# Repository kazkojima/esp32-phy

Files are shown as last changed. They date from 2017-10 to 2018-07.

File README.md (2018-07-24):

# ESP32 PHY

## hardware

ESP-WROOM-32 board with Ethernet made with KiCAD

  * esp32-tlk110

  * esp32-wslan8720

  There are choices for esp32-wslan8720 board. See 

https://kazkojima.github.io/esp32-phy2.html

for detail.

## apps

Applications with ESP32 PHY.

  * sbusconv - A serial to ether converter

See README in the application directory for detail.

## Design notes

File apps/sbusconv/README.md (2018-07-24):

# sbusconv

ESP32 serial-to-ether converter which uses ethernet PHYs. Supports LAN8720 and TK110 PHY. I'm using the hardwares [here](https://github.com/kazkojima/esp32-phy), though the any hardwares can be used with tiny changes on configuration or small fixes.

It converts the popular s.bus format serial RC signals to the RC UDP packets which Parrot bebop drone defines. The packet looks like:

```
struct __attribute__((packed)) rcpkt {
    uint32_t version;
    uint64_t timestamp_us;
    uint16_t sequence;
    uint16_t pwms[8];
};
```

One can easily change it to the mavlink packet, for example, if needed.

Currently no WiFi fuction is used, though you could easily add some controle or data transfer functions via WiFi, if you like.

There is only one unusual configuration item COPY_CH6_CH7 which copies the CH6 value to the CH7 value. My transmitter can't send CH7/CH8 values via s.bus although these channels are generally used for the convenient function like the emergency motor stop. This option makes it possible to use those function on my transmitter.

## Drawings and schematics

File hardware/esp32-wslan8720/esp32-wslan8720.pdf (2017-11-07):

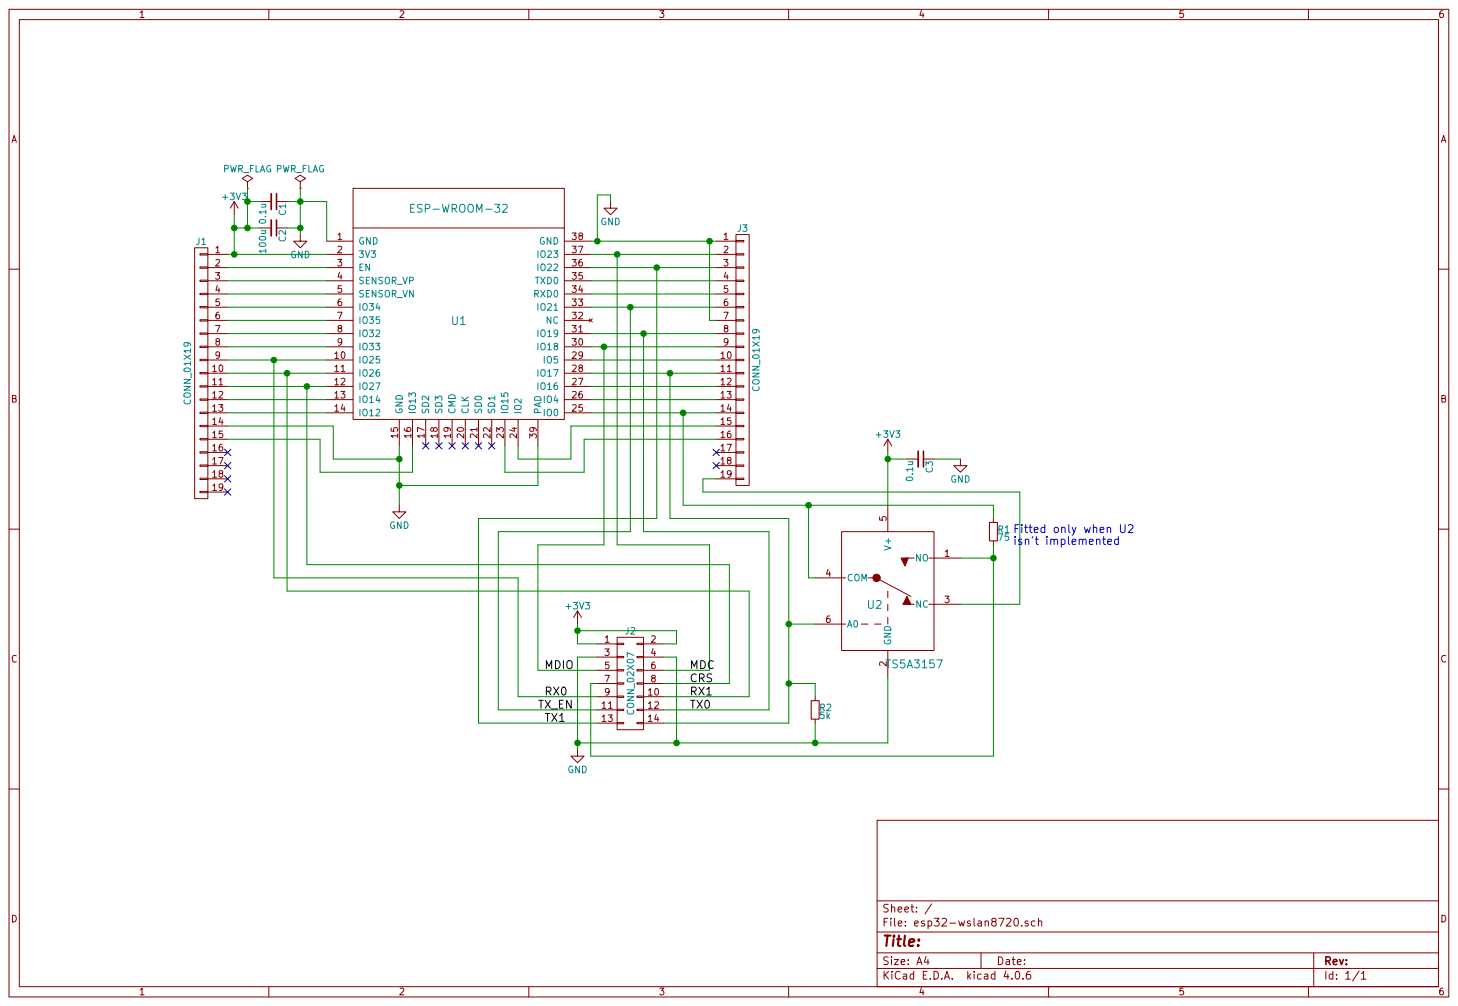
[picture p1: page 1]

2 | 3V3 2 EN 3 SENSOR_VP 4 SENSOR_VN 5 | 3

13 | | 14
14 | | | 15
15 | | | | 16

11 | | 12

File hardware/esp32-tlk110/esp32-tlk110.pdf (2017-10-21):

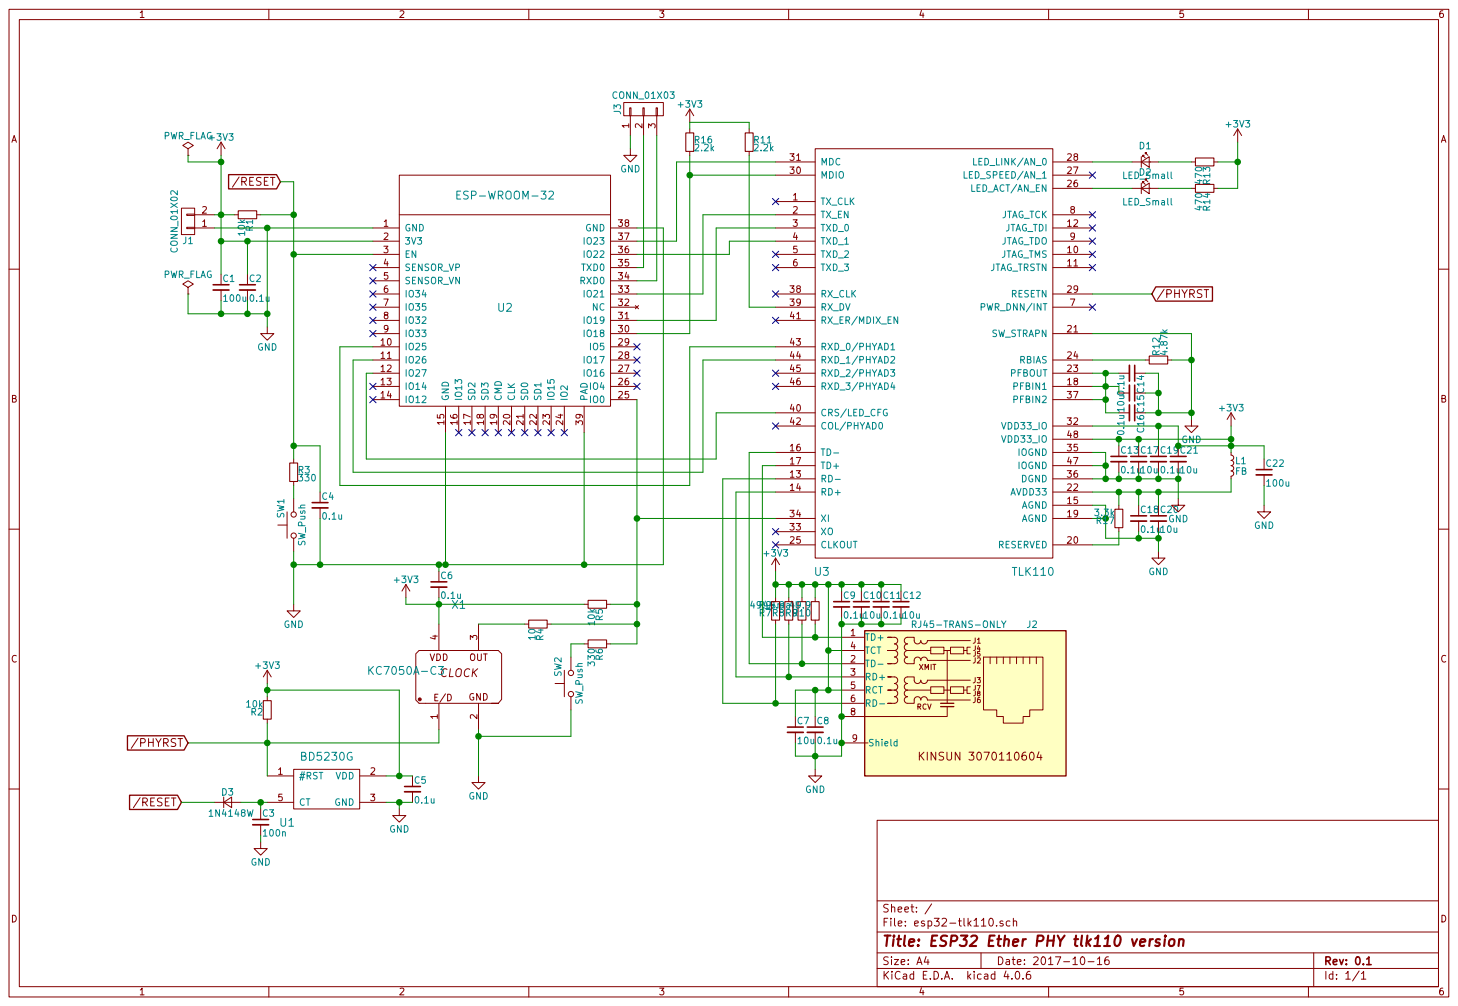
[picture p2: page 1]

File: esp32-tlk110.sch Sheet: /
Id: 1/1 Title: ESP32 Ether PHY tlk110 version

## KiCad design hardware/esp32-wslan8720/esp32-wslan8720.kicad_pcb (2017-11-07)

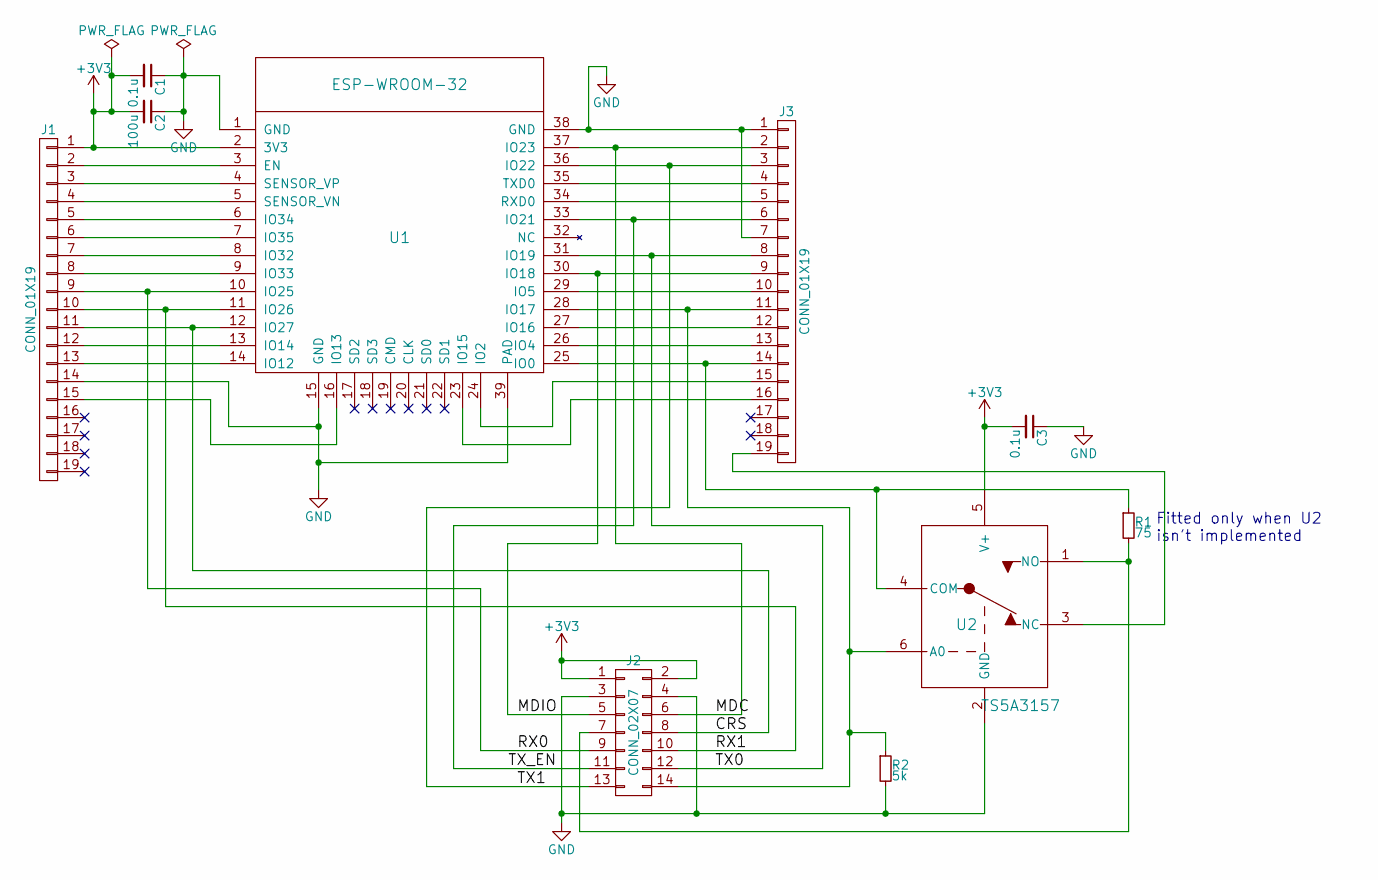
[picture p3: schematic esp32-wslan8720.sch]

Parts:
C1, C3: 0.1u; C_0603_HandSoldering
C2: 100u; C_1210_HandSoldering
J1, J3: CONN_01X19; Pin_Header_Straight_1x19_Pitch2.54mm
J2: CONN_02X07; Pin_Header_Angled_2x07_Pitch2.54mm
R1: 75; R_0603_HandSoldering
R2: 5k; R_0603_HandSoldering
U1: ESP-WROOM-32; ESP32-WROOM-fixed
U2: TS5A3157; SOT-23-6_Handsoldering

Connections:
+3V3: C1.2, C2.2, C3.2, J1.1, J2.1, J2.2, U1.2 (3V3), U2.5 (V+)
/CRS: J1.11, J2.8, U1.12 (IO27)
/MDC: J2.6, J3.2, U1.37 (IO23)
/MDIO: J2.5, J3.9, U1.30 (IO18)
/RX0: J1.9, J2.9, U1.10 (IO25)
/RX1: J1.10, J2.10, U1.11 (IO26)
/TX0: J2.12, J3.8, U1.31 (IO19)
/TX1: J2.13, J3.3, U1.36 (IO22)
/TX_EN: J2.11, J3.6, U1.33 (IO21)
GND: C1.1, C2.1, C3.1, J1.14, J2.3, J2.4, J3.1, J3.7, R2.2, U1.1 (GND), U1.15 (GND), U1.38 (GND), U1.39 (PAD), U2.2 (GND)
unnamed: J1.2, U1.3 (EN)
unnamed: J1.3, U1.4 (SENSOR_VP)
unnamed: J1.4, U1.5 (SENSOR_VN)
unnamed: J1.5, U1.6 (IO34)
unnamed: J1.6, U1.7 (IO35)
unnamed: J1.7, U1.8 (IO32)
unnamed: J1.8, U1.9 (IO33)
unnamed: J1.12, U1.13 (IO14)
unnamed: J1.13, U1.14 (IO12)
unnamed: J1.15, U1.16 (IO13)
unnamed: J2.7, R1.2, U2.1 (NO)
unnamed: J2.14, J3.11, R2.1, U1.28 (IO17), U2.6 (A0)
unnamed: J3.4, U1.35 (TXD0)
unnamed: J3.5, U1.34 (RXD0)
unnamed: J3.10, U1.29 (IO5)
unnamed: J3.12, U1.27 (IO16)
unnamed: J3.13, U1.26 (IO4)
unnamed: J3.14, R1.1, U1.25 (IO0), U2.4 (COM)
unnamed: J3.15, U1.24 (IO2)
unnamed: J3.16, U1.23 (IO15)
unnamed: J3.19, U2.3 (NC)

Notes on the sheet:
Fitted only when U2 isn't implemented

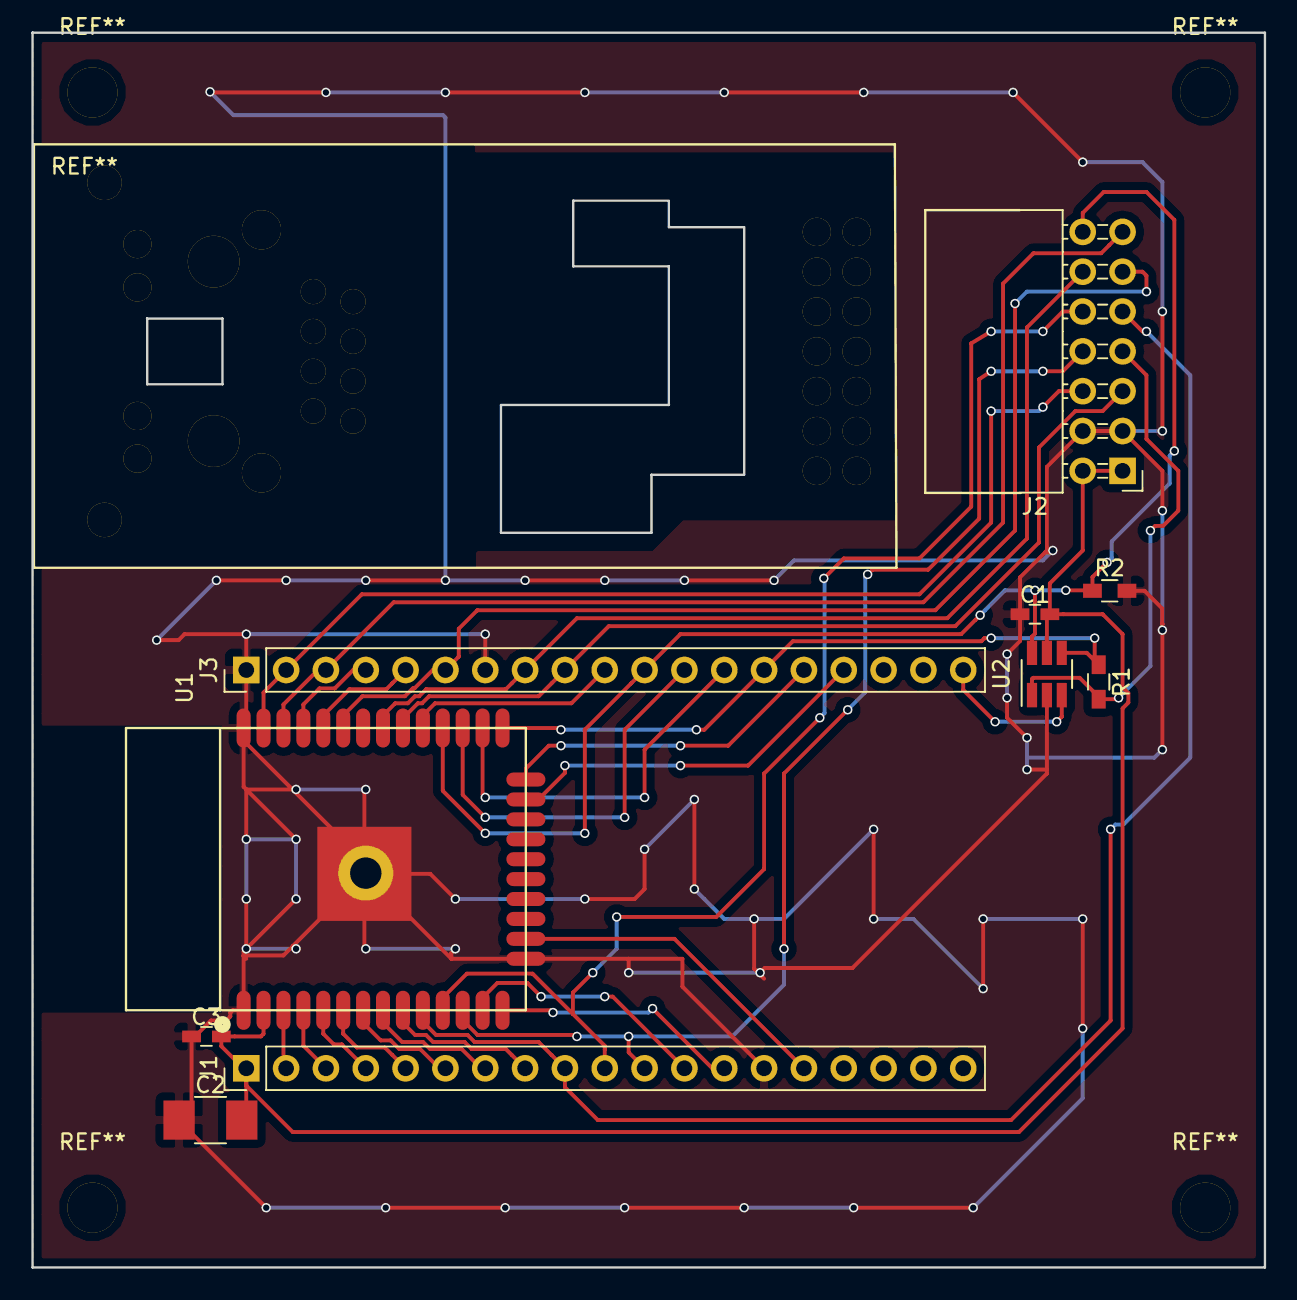
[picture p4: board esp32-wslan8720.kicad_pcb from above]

Board: 2 copper layers, 78.6 x 78.8 mm, 10 parts (0 on the bottom side), 31 nets.

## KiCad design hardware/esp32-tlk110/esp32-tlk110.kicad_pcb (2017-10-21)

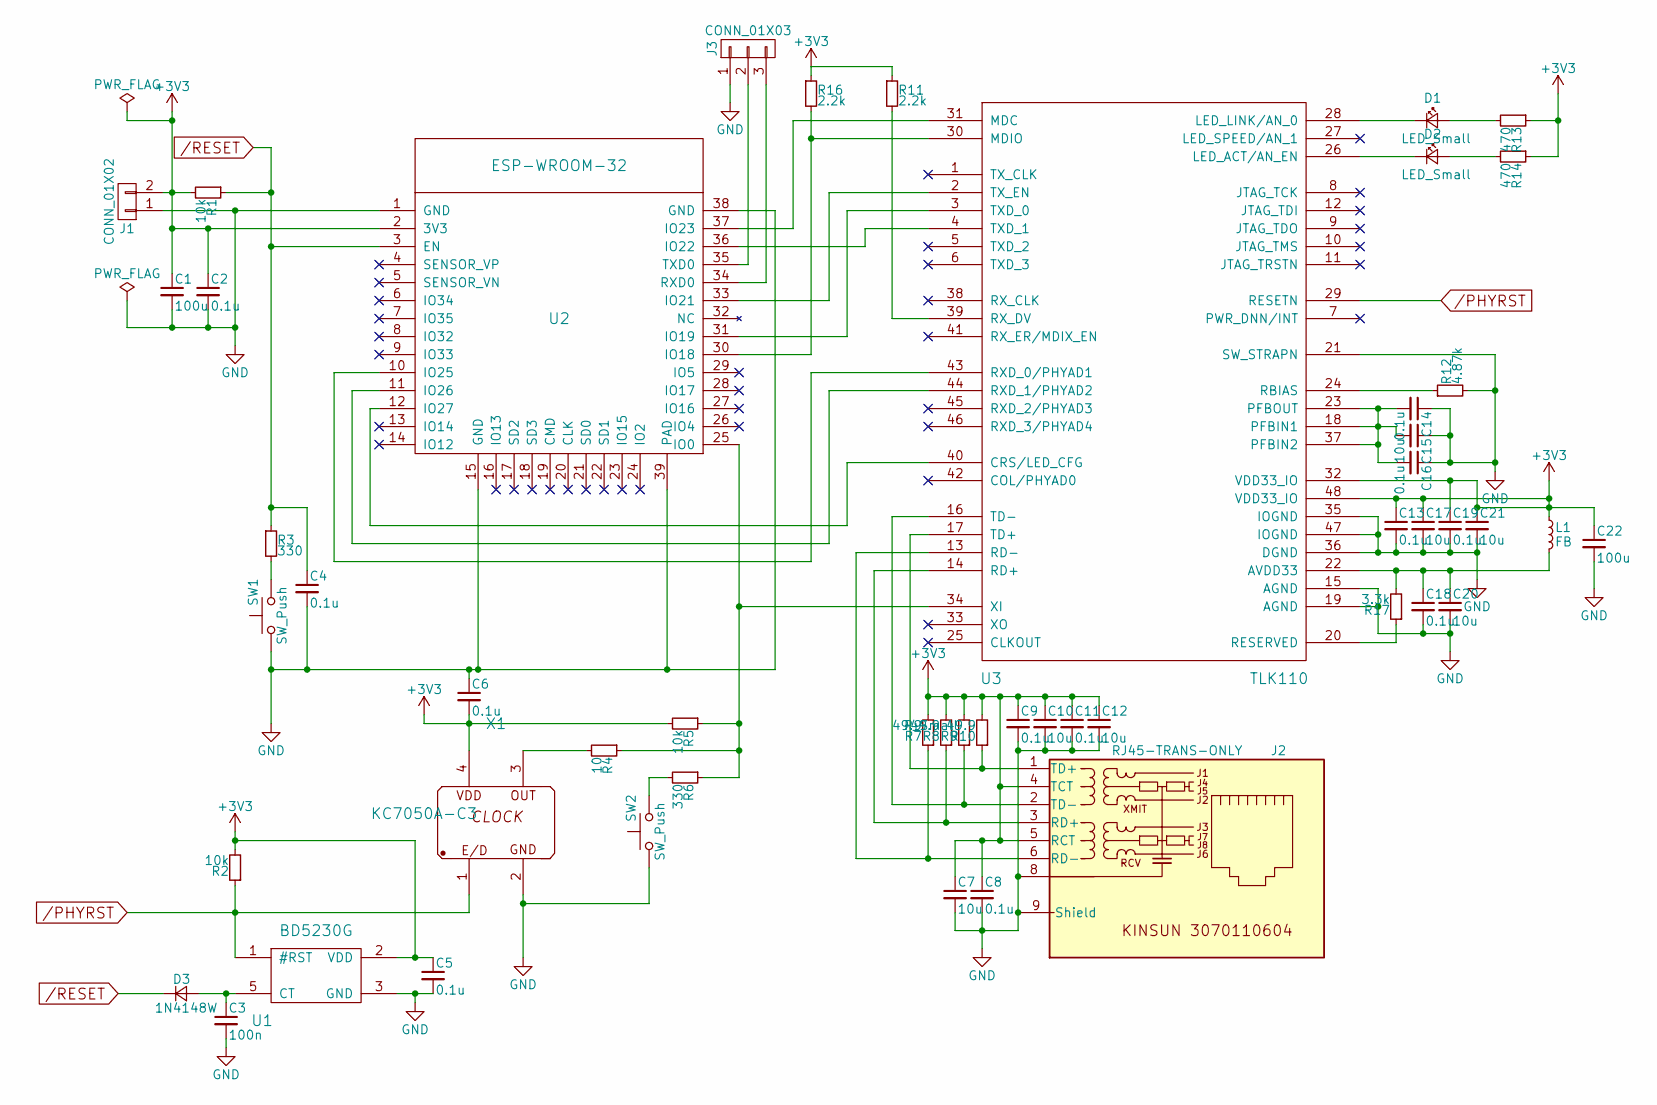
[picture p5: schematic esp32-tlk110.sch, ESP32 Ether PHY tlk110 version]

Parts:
C1: 100u; C_1210
C2, C4, C5, C6, C8, C9, C11, C13, C14, C16, C18, C19: 0.1u; C_0603
C3: 100n; C_0603
C7, C10, C12, C15, C17, C20, C21: 10u; C_0603
C22: 100u; R_1210_HandSoldering
D1, D2: LED_Small; D_0603
D3: 1N4148W; D_SOD-123
J1: CONN_01X02; Pin_Header_Straight_1x02_Pitch2.54mm
J2: RJ45-TRANS-ONLY; RJ45_Trans_Only
J3: CONN_01X03; Pin_Header_Straight_1x03_Pitch2.00mm
L1: FB; R_1210_HandSoldering
R1, R2, R5: 10k; R_0603
R3, R6: 330; R_0603
R4: 10; R_0603
R7, R8, R10: 49.9; R_0603
R9: R_Small; R_0603
R11, R16: 2.2k; R_0603
R12: 4.87k; R_0603
R13, R14: 470; R_0603
R17: 3.3k; R_0603
SW1, SW2: SW_Push; LS6J2M
U1: BD5230G; SOT-23-5_HandSoldering
U2: ESP-WROOM-32; ESP32-WROOM-fixed
U3: TLK110; LQFP-48_7x7mm_Pitch0.5mm
X1: KC7050A-C3; kyocera_kc7050a_c5

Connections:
+3V3: C1.1, C2.1, C5.1, C6.2, C7.1, C8.1, C9.1, C10.1, C11.1, C12.1, C13.1, C17.1, C19.1, C21.1, C22.1, J1.2, J2.4 (TCT), J2.5 (RCT), L1.1, R1.2, R2.2, R5.2, R7.2, R8.2, R9.2, R10.2, R11.1, R13.1, R14.1, R16.1, U1.2 (VDD), U2.2 (3V3), U3.32 (VDD33_IO), U3.48 (VDD33_IO), X1.4 (VDD)
/PHYRST: R2.1, U1.1 (#RST), U3.29 (RESETN), X1.1 (STANDBY)
/RESET: C4.1, D3.1 (K), R1.1, R3.1, U2.3 (EN)
GND: C1.2, C2.2, C3.2, C4.2, C5.2, C6.1, C7.2, C8.2, C9.2, C10.2, C11.2, C12.2, C13.2, C14.1, C15.1, C16.1, C17.2, C18.2, C19.2, C20.2, C21.2, C22.2, J1.1, J2.8, J2.9 (Shield), J3.1, R12.2, SW1.1, SW2.1, U1.3 (GND), U2.1 (GND), U2.15 (GND), U2.38 (GND), U2.39 (PAD), U3.15 (AGND), U3.19 (AGND), U3.21 (SW_STRAPN), U3.35 (IOGND), U3.36 (DGND), U3.47 (IOGND), X1.2 (GND)
unnamed: C3.1, D3.2 (A), U1.5 (CT)
unnamed: C14.2, C15.2, C16.2, U3.18 (PFBIN1), U3.23 (PFBOUT), U3.37 (PFBIN2)
unnamed: C18.1, C20.1, L1.2, R17.2, U3.22 (AVDD33)
unnamed: D1.1 (K), U3.28 (LED_LINK/AN_0)
unnamed: D1.2 (A), R13.2
unnamed: D2.1 (K), U3.26 (LED_ACT/AN_EN)
unnamed: D2.2 (A), R14.2
unnamed: J2.1 (TD+), R10.1, U3.17 (TD+)
unnamed: J2.2 (TD-), R9.1, U3.16 (TD-)
unnamed: J2.3 (RD+), R8.1, U3.14 (RD+)
unnamed: J2.6 (RD-), R7.1, U3.13 (RD-)
unnamed: J3.2, U2.35 (TXD0)
unnamed: J3.3, U2.34 (RXD0)
unnamed: R3.2, SW1.2
unnamed: R4.1, R5.1, R6.1, U2.25 (IO0), U3.34 (XI)
unnamed: R4.2, X1.3 (OUT)
unnamed: R6.2, SW2.2
unnamed: R11.2, U3.39 (RX_DV)
unnamed: R12.1, U3.24 (RBIAS)
unnamed: R16.2, U2.30 (IO18), U3.30 (MDIO)
unnamed: R17.1, U3.20 (RESERVED)
unnamed: U2.10 (IO25), U3.43 (RXD_0/PHYAD1)
unnamed: U2.11 (IO26), U3.44 (RXD_1/PHYAD2)
unnamed: U2.12 (IO27), U3.40 (CRS/LED_CFG)
unnamed: U2.31 (IO19), U3.3 (TXD_0)
unnamed: U2.33 (IO21), U3.2 (TX_EN)
unnamed: U2.36 (IO22), U3.4 (TXD_1)
unnamed: U2.37 (IO23), U3.31 (MDC)

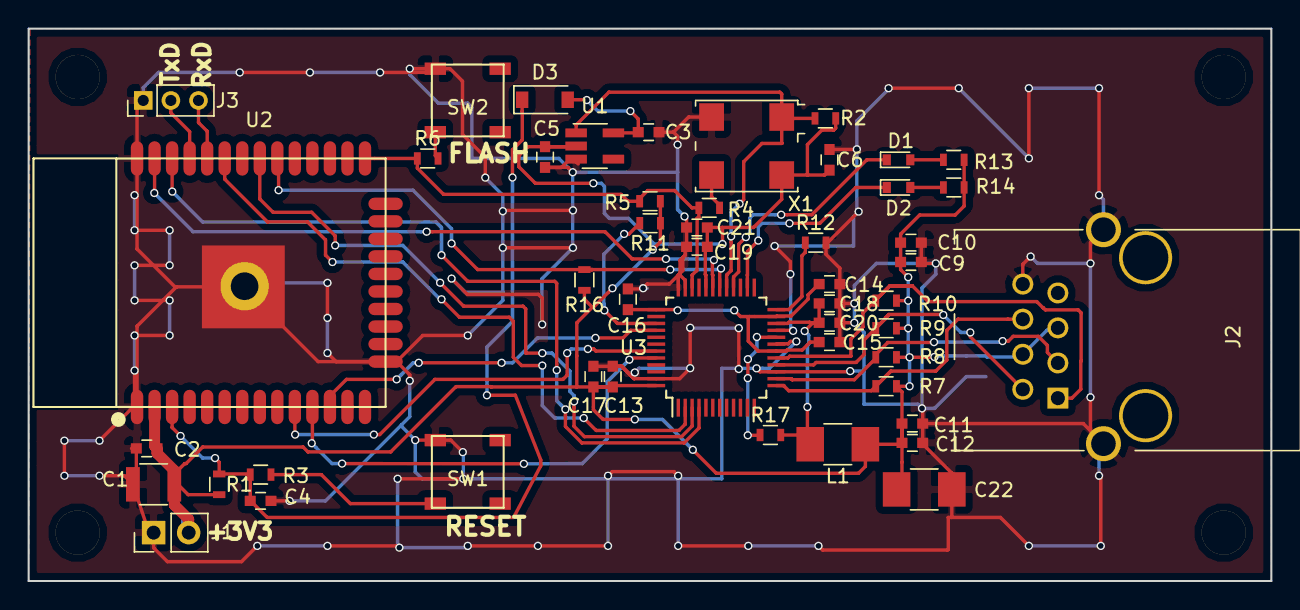
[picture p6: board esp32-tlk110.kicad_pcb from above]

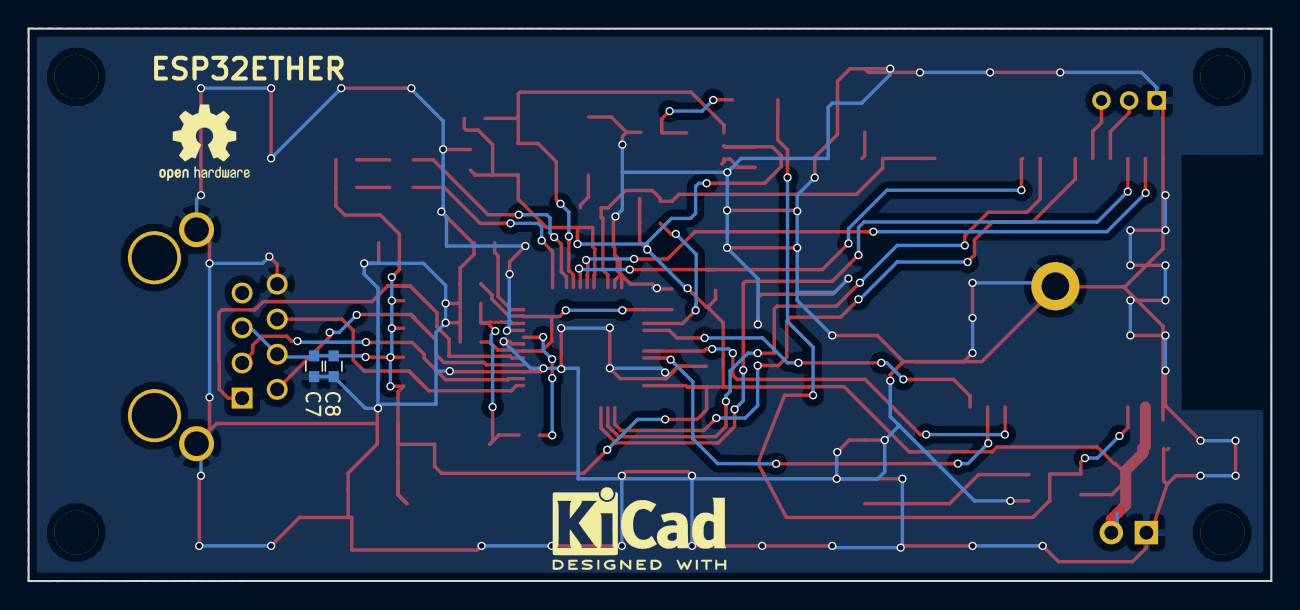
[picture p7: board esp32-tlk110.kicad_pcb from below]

Board: 2 copper layers, 90.0 x 40.0 mm, 51 parts (2 on the bottom side), 32 nets.

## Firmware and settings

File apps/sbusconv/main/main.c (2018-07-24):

/// -*- tab-width: 4; Mode: C++; c-basic-offset: 4; indent-tabs-mode: nil -*-

#include <stdio.h>
#include <stdlib.h>
#include <string.h>
#include "freertos/FreeRTOS.h"
#include "freertos/task.h"
#include "esp_wifi.h"
#include "esp_system.h"
#include "esp_log.h"
#include "esp_event.h"
#include "esp_event_loop.h"
#include "esp_now.h"
#include "esp_eth.h"
#include "esp_partition.h"

#include "tcpip_adapter.h"
#include "nvs_flash.h"
#include "nvs.h"
#include "driver/gpio.h"
#include "driver/spi_master.h"
#include "soc/gpio_struct.h"

#include "lwip/err.h"
#include "lwip/sockets.h"
#include "lwip/sys.h"
#include "lwip/netdb.h"

#if CONFIG_ENABLE_WIFI_AP
#define ADP_ADDR CONFIG_ADAPTOR_ADDRESS
#endif

#define UDP_SERVER CONFIG_UDP_SERVER_ADDRESS
#define UDP_PORT CONFIG_UDP_PORT

#ifdef CONFIG_PHY_LAN8720
#include "eth_phy/phy_lan8720.h"
#define DEFAULT_ETHERNET_PHY_CONFIG phy_lan8720_default_ethernet_config
#endif
#ifdef CONFIG_PHY_TLK110
#include "eth_phy/phy_tlk110.h"
#define DEFAULT_ETHERNET_PHY_CONFIG phy_tlk110_default_ethernet_config
#endif

#define PIN_PHY_POWER CONFIG_PHY_POWER_PIN
#define PIN_SMI_MDC   CONFIG_PHY_SMI_MDC_PIN
#define PIN_SMI_MDIO  CONFIG_PHY_SMI_MDIO_PIN

static const char *TAG = "sbus_adapter";

static bool client_connected = false;

esp_err_t event_handler(void *ctx, system_event_t *event)
{
    switch(event->event_id) {
    case SYSTEM_EVENT_STA_START:
      ESP_LOGI(TAG, "WiFi started");
      break;
    case SYSTEM_EVENT_AP_STADISCONNECTED:
       ESP_LOGI(TAG, "station:"MACSTR"leave, AID=%d\n",
                MAC2STR(event->event_info.sta_disconnected.mac),
                event->event_info.sta_disconnected.aid);
       client_connected = false;
       break;
     // TODO: case SYSTEM_EVENT_ETH_DISCONNECETED:
    default:
      break;
    }

    return ESP_OK;
}

#ifdef CONFIG_PHY_USE_POWER_PIN
/* This replaces the default PHY power on/off function with one that
   also uses a GPIO for power on/off.

   If this GPIO is not connected on your device (and PHY is always powered), you can use the default PHY-specific power
   on/off function rather than overriding with this one.
*/
static void phy_device_power_enable_via_gpio(bool enable)
{
    assert(DEFAULT_ETHERNET_PHY_CONFIG.phy_power_enable);

    if (!enable) {
        /* Do the PHY-specific power_enable(false) function before powering down */
        DEFAULT_ETHERNET_PHY_CONFIG.phy_power_enable(false);
    }

    if(enable == true) {
        gpio_set_level(PIN_PHY_POWER, 1);
        ESP_LOGD(TAG, "phy_device_power_enable(TRUE)");
    } else {
        gpio_set_level(PIN_PHY_POWER, 0);
        ESP_LOGD(TAG, "power_enable(FALSE)");
    }

    // Allow the power up/down to take effect, min 300us
    vTaskDelay(1);

    if (enable) {
        /* Run the PHY-specific power on operations now the PHY has power */
        DEFAULT_ETHERNET_PHY_CONFIG.phy_power_enable(true);
    }
}
#endif

static void eth_gpio_config_rmii(void)
{
    // RMII data pins are fixed:
    // TXD0 = GPIO19
    // TXD1 = GPIO22
    // TX_EN = GPIO21
    // RXD0 = GPIO25
    // RXD1 = GPIO26
    // CLK == GPIO0
    phy_rmii_configure_data_interface_pins();
    // MDC is GPIO 23, MDIO is GPIO 18
    phy_rmii_smi_configure_pins(PIN_SMI_MDC, PIN_SMI_MDIO);
}

static bool dhcp_done = false;
static in_addr_t eth_addr;
static int sockfd = -1;

void eth_task(void *pvParameter)
{
    tcpip_adapter_ip_info_t ip;
    memset(&ip, 0, sizeof(tcpip_adapter_ip_info_t));
    vTaskDelay(2000 / portTICK_PERIOD_MS);

    while (1) {

        vTaskDelay(2000 / portTICK_PERIOD_MS);

        if (tcpip_adapter_get_ip_info(ESP_IF_ETH, &ip))
            continue;

        if (!ip4_addr_isany_val(ip.ip)) {
            ESP_LOGI(TAG, "~~~~~~~~~~~");
            ESP_LOGI(TAG, "ETHIP:"IPSTR, IP2STR(&ip.ip));
            ESP_LOGI(TAG, "ETHPMASK:"IPSTR, IP2STR(&ip.netmask));
            ESP_LOGI(TAG, "ETHPGW:"IPSTR, IP2STR(&ip.gw));
            ESP_LOGI(TAG, "~~~~~~~~~~~");
            eth_addr = ip.ip.addr;
            dhcp_done = true;
            break;
        }
    }
    
    struct sockaddr_in saddr;
    struct sockaddr_in caddr;
    int rtn;

    printf("UDP client task starting...\n");

    int s = socket(AF_INET, SOCK_DGRAM, 0);
    if(s < 0) {
        printf("... Failed to allocate socket.\n");
        goto fail;
    }

    memset((char *) &caddr, 0, sizeof(caddr));
    caddr.sin_family = AF_INET;
    caddr.sin_addr.s_addr =  eth_addr;
    caddr.sin_port = htons(UDP_PORT);

    memset((char *) &saddr, 0, sizeof(saddr));
    saddr.sin_family = AF_INET;
    saddr.sin_addr.s_addr = inet_addr (UDP_SERVER);
    saddr.sin_port = htons(UDP_PORT);

    rtn = bind (s, (struct sockaddr *)&caddr, sizeof(caddr));
    if(rtn < 0) {
        printf("... Failed to bind socket.\n");
        vTaskDelay(1000 / portTICK_PERIOD_MS);
        close (s);
        goto fail;
    }

    rtn = connect(s, (struct sockaddr *) &saddr, sizeof(saddr));
    if (rtn < 0) {
        printf("... Failed to connect socket.\n");
        vTaskDelay(1000 / portTICK_PERIOD_MS);
        close (s);
        goto fail;
    }

    sockfd = s;

 fail:
    while(1) {
        vTaskDelay(2000 / portTICK_PERIOD_MS);
    }
}

#if CONFIG_ENABLE_WIFI_AP
static int wsockfd = -1;
static struct sockaddr_in cli_addr;

void wifi_task(void *pvParameter)
{
    while(sockfd < 0) {
        vTaskDelay(1000 / portTICK_PERIOD_MS);
    }

    int fd = socket(AF_INET, SOCK_DGRAM, 0);
    if (fd < 0) {
        printf("... Failed to create wifi socket.\n");
        goto fail;
    }

    int on = 1;
    setsockopt(fd, SOL_SOCKET, SO_REUSEADDR, &on, sizeof(int));

    struct sockaddr_in saddr;
    memset((char *) &saddr, 0, sizeof(saddr));
    saddr.sin_family = AF_INET;
    saddr.sin_port = htons(UDP_PORT);
    saddr.sin_addr.s_addr = inet_addr(ADP_ADDR);
    if (bind(fd, (struct sockaddr *)&saddr, sizeof(saddr)) < 0) {
        int err;
        u32_t optlen = sizeof(int);
        getsockopt(fd, SOL_SOCKET, SO_ERROR, &err, &optlen);
        ESP_LOGW(TAG, "socket error %d %s", err, strerror(err));
        printf("... Failed to bind wifi socket.\n");
        close(fd);
        goto fail;
    }

    wsockfd = fd;

 fail:
    while(1) {
        vTaskDelay(2000 / portTICK_PERIOD_MS);
    }
}
#endif

struct __attribute__((packed)) rcpkt {
    uint32_t version;
    uint64_t timestamp_us;
    uint16_t sequence;
    uint16_t pwms[8];
};

xQueueHandle sbus_queue = NULL;

static void send_task(void *arg)
{
    while(sockfd < 0) {
        vTaskDelay(1000 / portTICK_PERIOD_MS);
    }

    uint16_t rcpkt_count = 0;

    ESP_LOGI(TAG, "Starting loop to sending udp packets");
    while(1) {
        uint16_t pwm[8];
        if (xQueueReceive(sbus_queue, (uint8_t *)pwm, portMAX_DELAY) == pdTRUE) {
            if (CONFIG_COPY_CH6_CH7) {
                uint16_t tmp = pwm[6];
                pwm[6] = pwm[5];
                pwm[5] = tmp;
            }

            struct rcpkt pkt;
            memset(&pkt, 0, sizeof(pkt));
            pkt.version = 2;
            pkt.sequence = rcpkt_count++;
            pkt.timestamp_us = ((uint64_t)1000) * xTaskGetTickCount();
            for(int i=0; i<8; i++)
                pkt.pwms[i] = pwm[i];

            int n = send(sockfd, &pkt, sizeof(pkt), 0);
            //printf("%d byte sent\n", n);
            if (n < 0) {
                printf("Failed to send udp packet\n");
            }
        }
    }
}

void sbus_task(void *);

void app_main(void)
{
    esp_err_t ret = ESP_OK;

    nvs_flash_init();
    tcpip_adapter_init();
    ESP_ERROR_CHECK( esp_event_loop_init(event_handler, NULL) );
#if CONFIG_ENABLE_WIFI_AP
    tcpip_adapter_ip_info_t info = { 0, };
    ip4addr_aton(ADP_ADDR, &info.ip);
    ip4addr_aton(ADP_ADDR, &info.gw);
    IP4_ADDR(&info.netmask, 255, 255, 255, 0);
    ESP_ERROR_CHECK(tcpip_adapter_dhcps_stop(TCPIP_ADAPTER_IF_AP));
    ESP_ERROR_CHECK(tcpip_adapter_set_ip_info(TCPIP_ADAPTER_IF_AP, &info));
    ESP_ERROR_CHECK(tcpip_adapter_dhcps_start(TCPIP_ADAPTER_IF_AP));    
    wifi_init_config_t cfg = WIFI_INIT_CONFIG_DEFAULT();
    ESP_ERROR_CHECK(esp_wifi_init(&cfg));
    wifi_config_t wifi_config = {
        .ap = {
            .ssid = CONFIG_SSID,
            .ssid_len = 0,
            .max_connection = 1,
            .password = CONFIG_SSID_PASSWORD,
            .authmode = WIFI_AUTH_WPA_WPA2_PSK
        },
    };
    ESP_ERROR_CHECK(esp_wifi_set_mode(WIFI_MODE_AP));
    ESP_ERROR_CHECK(esp_wifi_set_config(ESP_IF_WIFI_AP, &wifi_config));
    ESP_ERROR_CHECK(esp_wifi_start());
#endif

    eth_config_t config = DEFAULT_ETHERNET_PHY_CONFIG;
    /* Set the PHY address in the example configuration */
    config.phy_addr = CONFIG_PHY_ADDRESS;
    config.gpio_config = eth_gpio_config_rmii;
    config.tcpip_input = tcpip_adapter_eth_input;

#ifdef CONFIG_PHY_USE_POWER_PIN
    gpio_pad_select_gpio(PIN_PHY_POWER);
    gpio_set_direction(PIN_PHY_POWER,GPIO_MODE_OUTPUT);
    gpio_set_level(PIN_PHY_POWER, 0);
    ESP_LOGD(TAG, "power_enable(FALSE)");
    
    /* Replace the default 'power enable' function with an example-specific
       one that toggles a power GPIO. */
    config.phy_power_enable = phy_device_power_enable_via_gpio;
#endif
    vTaskDelay(1000 / portTICK_PERIOD_MS);

    ret = esp_eth_init(&config);

    if(ret == ESP_OK) {
        esp_eth_enable();
        xTaskCreate(eth_task, "eth_task", 2048, NULL, 5, NULL);
    }

    sbus_queue = xQueueCreate(4, 8*sizeof(uint16_t));

#if CONFIG_ENABLE_WIFI_AP
    xTaskCreate(wifi_task, "wifi_task", 2048, NULL, 5, NULL);
#endif

    xTaskCreate(sbus_task, "sbus_task", 2048, NULL, 6, NULL);
    xTaskCreate(send_task, "send_task", 2048, NULL, 7, NULL);

    gpio_set_direction(GPIO_NUM_2, GPIO_MODE_OUTPUT);
    int level = 0;
    while (true) {
        gpio_set_level(GPIO_NUM_2, level);
        level = !level;
        vTaskDelay(1000 / portTICK_PERIOD_MS);
    }
}

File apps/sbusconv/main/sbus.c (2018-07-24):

/// -*- tab-width: 4; Mode: C++; c-basic-offset: 4; indent-tabs-mode: nil -*-

#include <stdio.h>
#include <stdlib.h>
#include <string.h>
#include "freertos/FreeRTOS.h"
#include "freertos/task.h"
#include "esp_wifi.h"
#include "esp_system.h"
#include "esp_event.h"
#include "esp_event_loop.h"
#include "nvs.h"
#include "driver/uart.h"
#include "freertos/queue.h"
#include "esp_log.h"
#include "soc/uart_struct.h"

#define UART_SBUS UART_NUM_2
#define SBUS_TXD 17
#define SBUS_RXD 16
#define BUF_SIZE 256

static void uart_init()
{
    uart_config_t uart_config = {
       .baud_rate = 100000,
       .data_bits = UART_DATA_8_BITS,
       .parity = UART_PARITY_EVEN,
       .stop_bits = UART_STOP_BITS_1,
       .flow_ctrl = UART_HW_FLOWCTRL_DISABLE,
       .rx_flow_ctrl_thresh = 122,
    };

    uart_param_config(UART_SBUS, &uart_config);
    uart_set_pin(UART_SBUS, SBUS_TXD, SBUS_RXD,
                 UART_PIN_NO_CHANGE, UART_PIN_NO_CHANGE);
    uart_set_line_inverse(UART_SBUS, UART_INVERSE_RXD);
    uart_driver_install(UART_SBUS, BUF_SIZE, BUF_SIZE, 0, NULL, 0);

    printf("uart2 initialized for SBUS input\n");
}

#define SBUS_NUM_CHANNELS 16
#define SBUS_FRAME_SIZE	25
#define SBUS_FLAGS_BYTE	23
#define SBUS_FAILSAFE_BIT 3
#define SBUS_FRAMELOST_BIT 2

struct {
  uint16_t bytes[SBUS_FRAME_SIZE]; // including start bit, parity and stop bits
  uint16_t bit_ofs;
} sbus_state;

static uint16_t pwm_values[SBUS_NUM_CHANNELS];

/* S.BUS decoder matrix based on src/modules/px4iofirmware/sbus.c from
   PX4Firmware.

   Each channel value can come from up to 3 input bytes. Each row in the
   matrix describes up to three bytes, and each entry gives:

   - byte offset in the data portion of the frame
   - right shift applied to the data byte
   - mask for the data byte
   - left shift applied to the result into the channel value
 */
struct sbus_bit_pick {
	uint8_t byte;
	uint8_t rshift;
	uint8_t mask;
	uint8_t lshift;
};

static const struct sbus_bit_pick sbus_decoder[SBUS_NUM_CHANNELS][3] = {
  /*  0 */ { { 0, 0, 0xff, 0}, { 1, 0, 0x07, 8}, { 0, 0, 0x00,  0} },
  /*  1 */ { { 1, 3, 0x1f, 0}, { 2, 0, 0x3f, 5}, { 0, 0, 0x00,  0} },
  /*  2 */ { { 2, 6, 0x03, 0}, { 3, 0, 0xff, 2}, { 4, 0, 0x01, 10} },
  /*  3 */ { { 4, 1, 0x7f, 0}, { 5, 0, 0x0f, 7}, { 0, 0, 0x00,  0} },
  /*  4 */ { { 5, 4, 0x0f, 0}, { 6, 0, 0x7f, 4}, { 0, 0, 0x00,  0} },
  /*  5 */ { { 6, 7, 0x01, 0}, { 7, 0, 0xff, 1}, { 8, 0, 0x03,  9} },
  /*  6 */ { { 8, 2, 0x3f, 0}, { 9, 0, 0x1f, 6}, { 0, 0, 0x00,  0} },
  /*  7 */ { { 9, 5, 0x07, 0}, {10, 0, 0xff, 3}, { 0, 0, 0x00,  0} },
  /*  8 */ { {11, 0, 0xff, 0}, {12, 0, 0x07, 8}, { 0, 0, 0x00,  0} },
  /*  9 */ { {12, 3, 0x1f, 0}, {13, 0, 0x3f, 5}, { 0, 0, 0x00,  0} },
  /* 10 */ { {13, 6, 0x03, 0}, {14, 0, 0xff, 2}, {15, 0, 0x01, 10} },
  /* 11 */ { {15, 1, 0x7f, 0}, {16, 0, 0x0f, 7}, { 0, 0, 0x00,  0} },
  /* 12 */ { {16, 4, 0x0f, 0}, {17, 0, 0x7f, 4}, { 0, 0, 0x00,  0} },
  /* 13 */ { {17, 7, 0x01, 0}, {18, 0, 0xff, 1}, {19, 0, 0x03,  9} },
  /* 14 */ { {19, 2, 0x3f, 0}, {20, 0, 0x1f, 6}, { 0, 0, 0x00,  0} },
  /* 15 */ { {20, 5, 0x07, 0}, {21, 0, 0xff, 3}, { 0, 0, 0x00,  0} }
};

static bool
sbus_decode (const uint8_t frame[SBUS_FRAME_SIZE])
{
    /* check frame boundary markers to avoid out-of-sync cases */
    if (frame[0] != 0x0f)
        return false;

    /* use the decoder matrix to extract channel data */
    for (int ch = 0; ch < SBUS_NUM_CHANNELS; ch++) {
        unsigned value = 0;

        for (int pick = 0; pick < 3; pick++) {
            const struct sbus_bit_pick *decode = &sbus_decoder[ch][pick];

            if (decode->mask != 0) {
                unsigned piece = frame[1 + decode->byte];
                piece >>= decode->rshift;
                piece &= decode->mask;
                piece <<= decode->lshift;
                value |= piece;
            }
        }

        /* Map SBUS range.
            200 -> 1000micro
           1800 -> 2000micro
        */
        pwm_values[ch] = (uint16_t)((value-200)/1.6 +.5f) + 1000;
        //printf("%d: %d\n", ch, pwm_values[ch]);
    }

  return true;
}

extern xQueueHandle sbus_queue;

// If no input for 5000us, skip to next mark.
#define FRAME_SPACE (5 / portTICK_PERIOD_MS)

void sbus_read(void)
{
    uint8_t c;
    uint8_t buf[25];
    int n, count = 0;
    bool start;

    start = false;
    while (count < 25) {
        n = uart_read_bytes(UART_SBUS, &c, 1, portMAX_DELAY);
        if (n <= 0)
            break;
        //printf("0x%02x ", c);
        if (!start)
            {
                if (c != 0x0f)
                    continue;
                start = true;
            }
        buf[count++] = c;
        if (count < 25)
            continue;
        if (buf[24] == 0x0 || (buf[24] & 0xc4) == 0x4) {
            //dump_frame (buf);
            if (sbus_decode(buf)) {
                if (xQueueSend(sbus_queue, pwm_values, 8*sizeof(uint16_t))
                    != pdTRUE) {
                    //printf("fail to queue pwm_values\n");
                }
            }
            break;
        }
        // Skip to end byte
        while (uart_read_bytes(UART_SBUS, &c, 1, portMAX_DELAY) == 1
               && !(c == 0x0 || (c & 0xc4) == 0x4))
            ;
        break;
    }
}

void sbus_task(void *arg)
{
    uart_init();

    while(1) {
        sbus_read();
    }
}

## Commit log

2017-10-21 Inital commit
    [esp32-tlk110-B.Cu.gbr, esp32-tlk110-B.Mask.gbr, esp32-tlk110-B.SilkS.gbr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]
2017-11-07 Add hardware/esp32-wslan8720.
    [esp32-wslan8720-B.Cu.gbr, esp32-wslan8720-B.Mask.gbr, esp32-wslan8720-B.SilkS.gbr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]
